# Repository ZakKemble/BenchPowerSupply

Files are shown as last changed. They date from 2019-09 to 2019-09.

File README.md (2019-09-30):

Bench Power Supply
==================

A 7.5A adjustable output bench power supply designed to be used with a 19V laptop power supply.

https://blog.zakkemble.net/laptop-bench-power-supply/

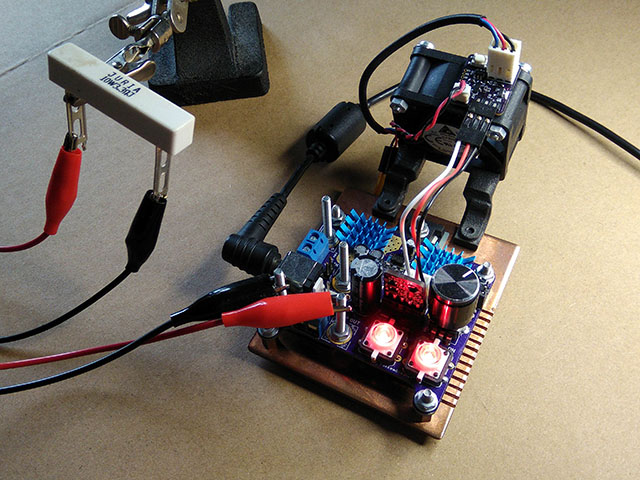
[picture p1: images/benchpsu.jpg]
PSU pic


---

Zak Kemble

contact@zakkemble.net

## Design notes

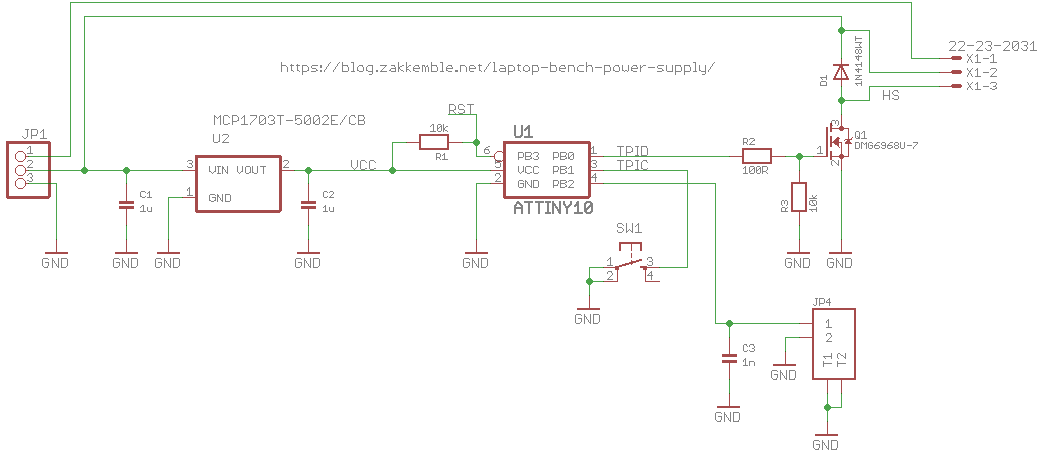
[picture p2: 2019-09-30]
hardware/fanCtrl_schematic.png

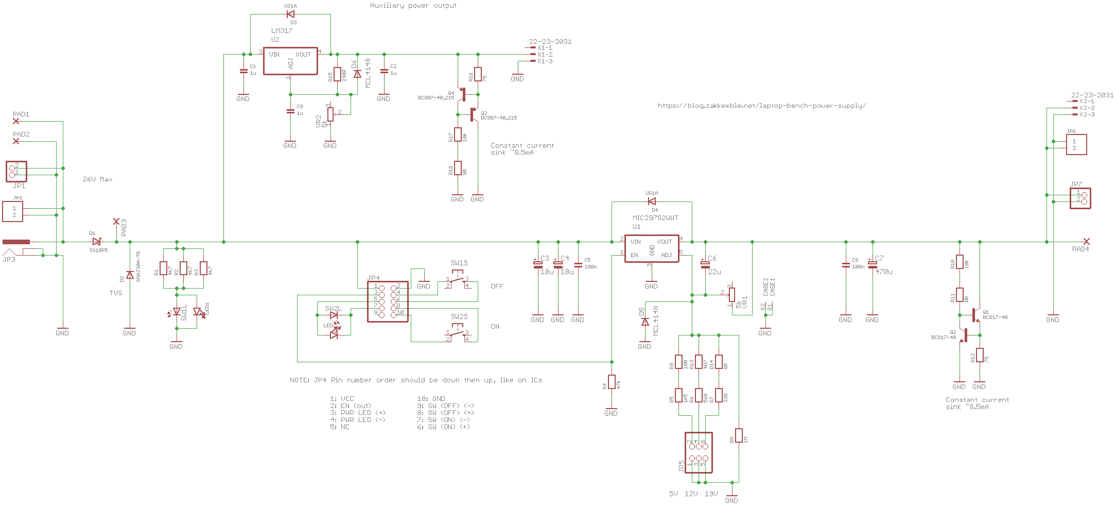
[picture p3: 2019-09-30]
hardware/reg_MIC29752_schematic.png

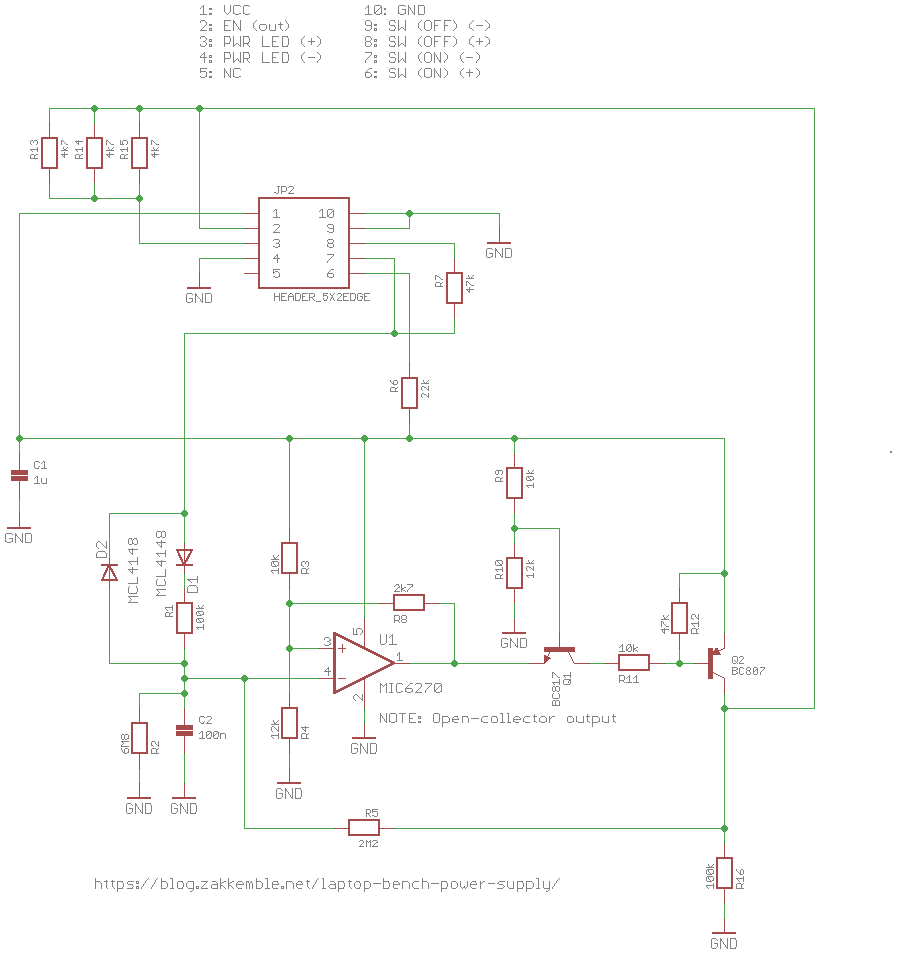
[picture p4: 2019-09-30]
hardware/control1_schematic.png

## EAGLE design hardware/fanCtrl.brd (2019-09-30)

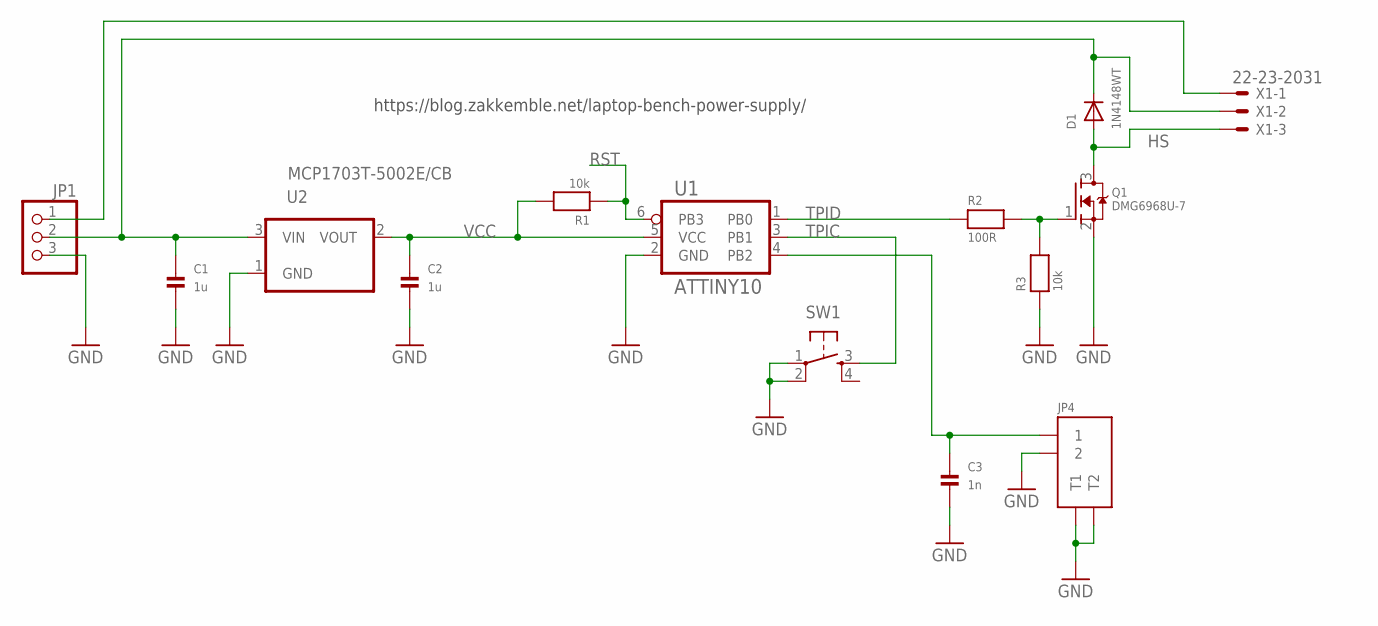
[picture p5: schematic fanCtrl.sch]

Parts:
C1, C2: 1u; _0603MP
C3: 1n; 0402_SMALL
D1: 1N4148WT; SOD-523
JP1: PINHD-1X3; 1X03
JP4: 2WAY
Q1: DMG6968U-7; SOT23-W
R1, R3: 10k; 0402_SMALL
R2: 100R; 0402_SMALL
SW1: SPST_TACTG75_3X4; TACT_SMD5
U1: ATTINY10; SOT23-6_SM_PAD
U2: MCP1703T-5002E/CB; SOT-23
X1: 22-23-2031

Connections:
GND: C1.2, C2.2, C3.2, JP1.3, JP4.P$2 (2), JP4.TAB$1 (T1), JP4.TAB$2 (T2), Q1.2 (S), R3.1, SW1.1, SW1.2 (P1), U1.2 (GND), U2.1 (GND)
HS: D1.A, Q1.3 (D), X1.3
unnamed: Q1.1 (G), R2.2, R3.2
unnamed: C3.1, JP4.P$1 (1), U1.4 (PB2)
unnamed: C1.1, D1.K (C), JP1.2, U2.3 (VIN), X1.2
unnamed: JP1.1, X1.1
RST: R1.1, U1.6 (PB3)
TPIC: SW1.3 (S), U1.3 (PB1)
TPID: R2.1, U1.1 (PB0)
VCC: C2.1, R1.2, U1.5 (VCC), U2.2 (VOUT)

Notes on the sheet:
https://blog.zakkemble.net/laptop-bench-power-supply/

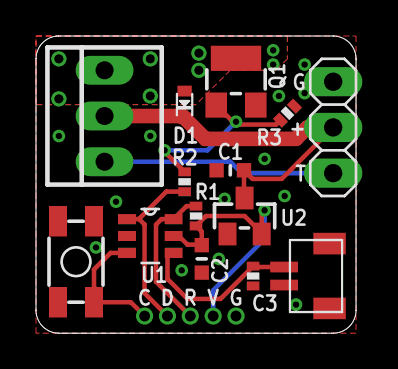
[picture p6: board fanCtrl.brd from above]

Board: 2 copper layers, 17.8 x 16.5 mm, 14 parts (0 on the bottom side), 10 nets.

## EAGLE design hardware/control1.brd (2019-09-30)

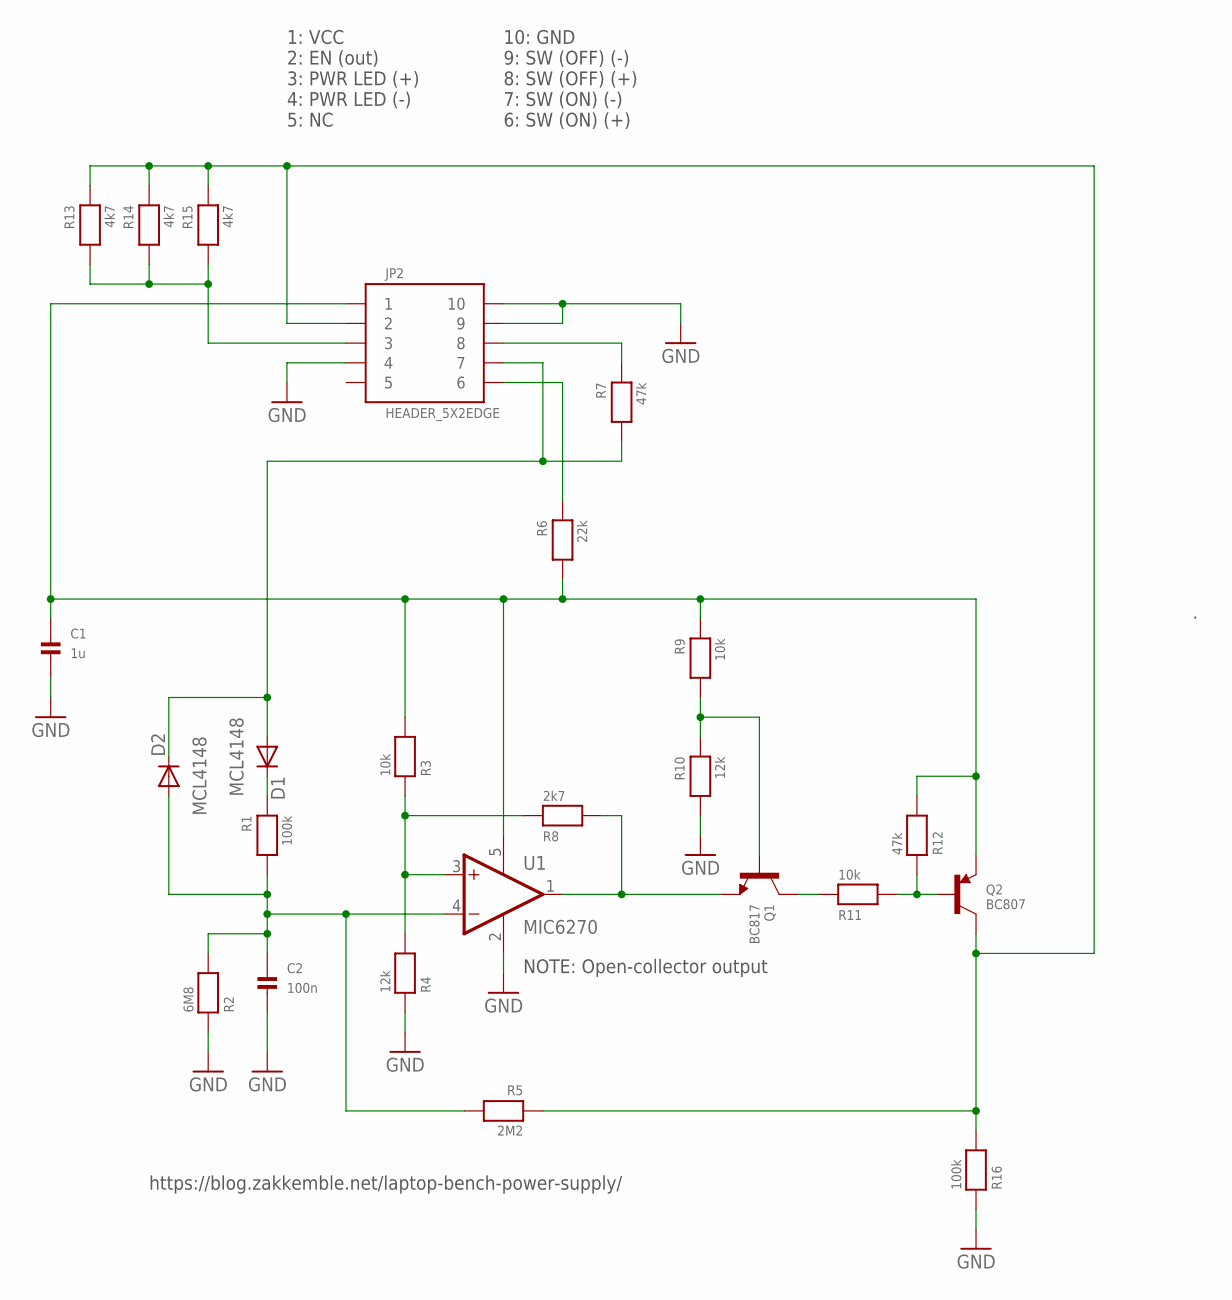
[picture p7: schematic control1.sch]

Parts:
C1: 1u; 0402
C2: 100n; _0603MP
D1, D2: MCL4148; MICROMELF-R
JP2: HEADER_5X2EDGE; HEADER_EDGE_5X2
Q1: BC817; SOT23-WIDE
Q2: BC807; SOT23-WIDE
R1, R16: 100k; 0402
R2: 6M8; 0402
R3, R9, R11: 10k; 0402
R4, R10: 12k; 0402
R5: 2M2; 0402
R6: 22k; 0402
R7, R12: 47k; 0402
R8: 2k7; 0402
R13, R14, R15: 4k7; 0402
U1: MIC6270; SOT95P275X110-5N

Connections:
GND: C1.2, C2.2, JP2.4, JP2.9, JP2.10, R2.1, R4.1, R10.2, R16.1, U1.2 (GND)
unnamed: C1.1, JP2.1, Q2.2 (E), R3.2, R6.2, R9.1, R12.2, U1.5 (V+)
unnamed: JP2.8, R7.1
unnamed: JP2.3, R13.2, R14.2, R15.2
unnamed: R3.1, R4.2, R8.1, U1.3 (+IN)
unnamed: C2.1, D2.A, R1.2, R2.2, R5.2, U1.4 (-IN)
unnamed: JP2.6, R6.1
unnamed: JP2.2, Q2.3 (C), R5.1, R13.1, R14.1, R15.1, R16.2
unnamed: Q1.3 (C), R11.1
unnamed: Q2.1 (B), R11.2, R12.1
unnamed: Q1.2 (E), R8.2, U1.1 (OUT)
unnamed: Q1.1 (B), R9.2, R10.1
unnamed: D1.A, D2.C, JP2.7, R7.2
unnamed: D1.C, R1.1

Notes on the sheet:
NOTE: Open-collector output
1: VCC 2: EN (out) 3: PWR LED (+) 4: PWR LED (-) 5: NC
10: GND 9: SW (OFF) (-) 8: SW (OFF) (+) 7: SW (ON) (-) 6: SW (ON) (+)
https://blog.zakkemble.net/laptop-bench-power-supply/

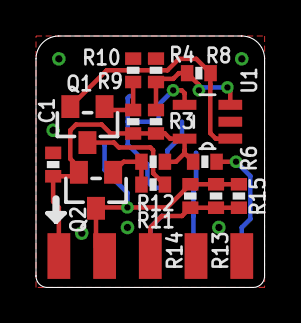
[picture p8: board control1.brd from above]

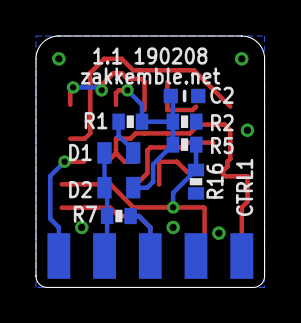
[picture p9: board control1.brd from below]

Board: 2 copper layers, 12.7 x 14.0 mm, 24 parts (8 on the bottom side), 14 nets.

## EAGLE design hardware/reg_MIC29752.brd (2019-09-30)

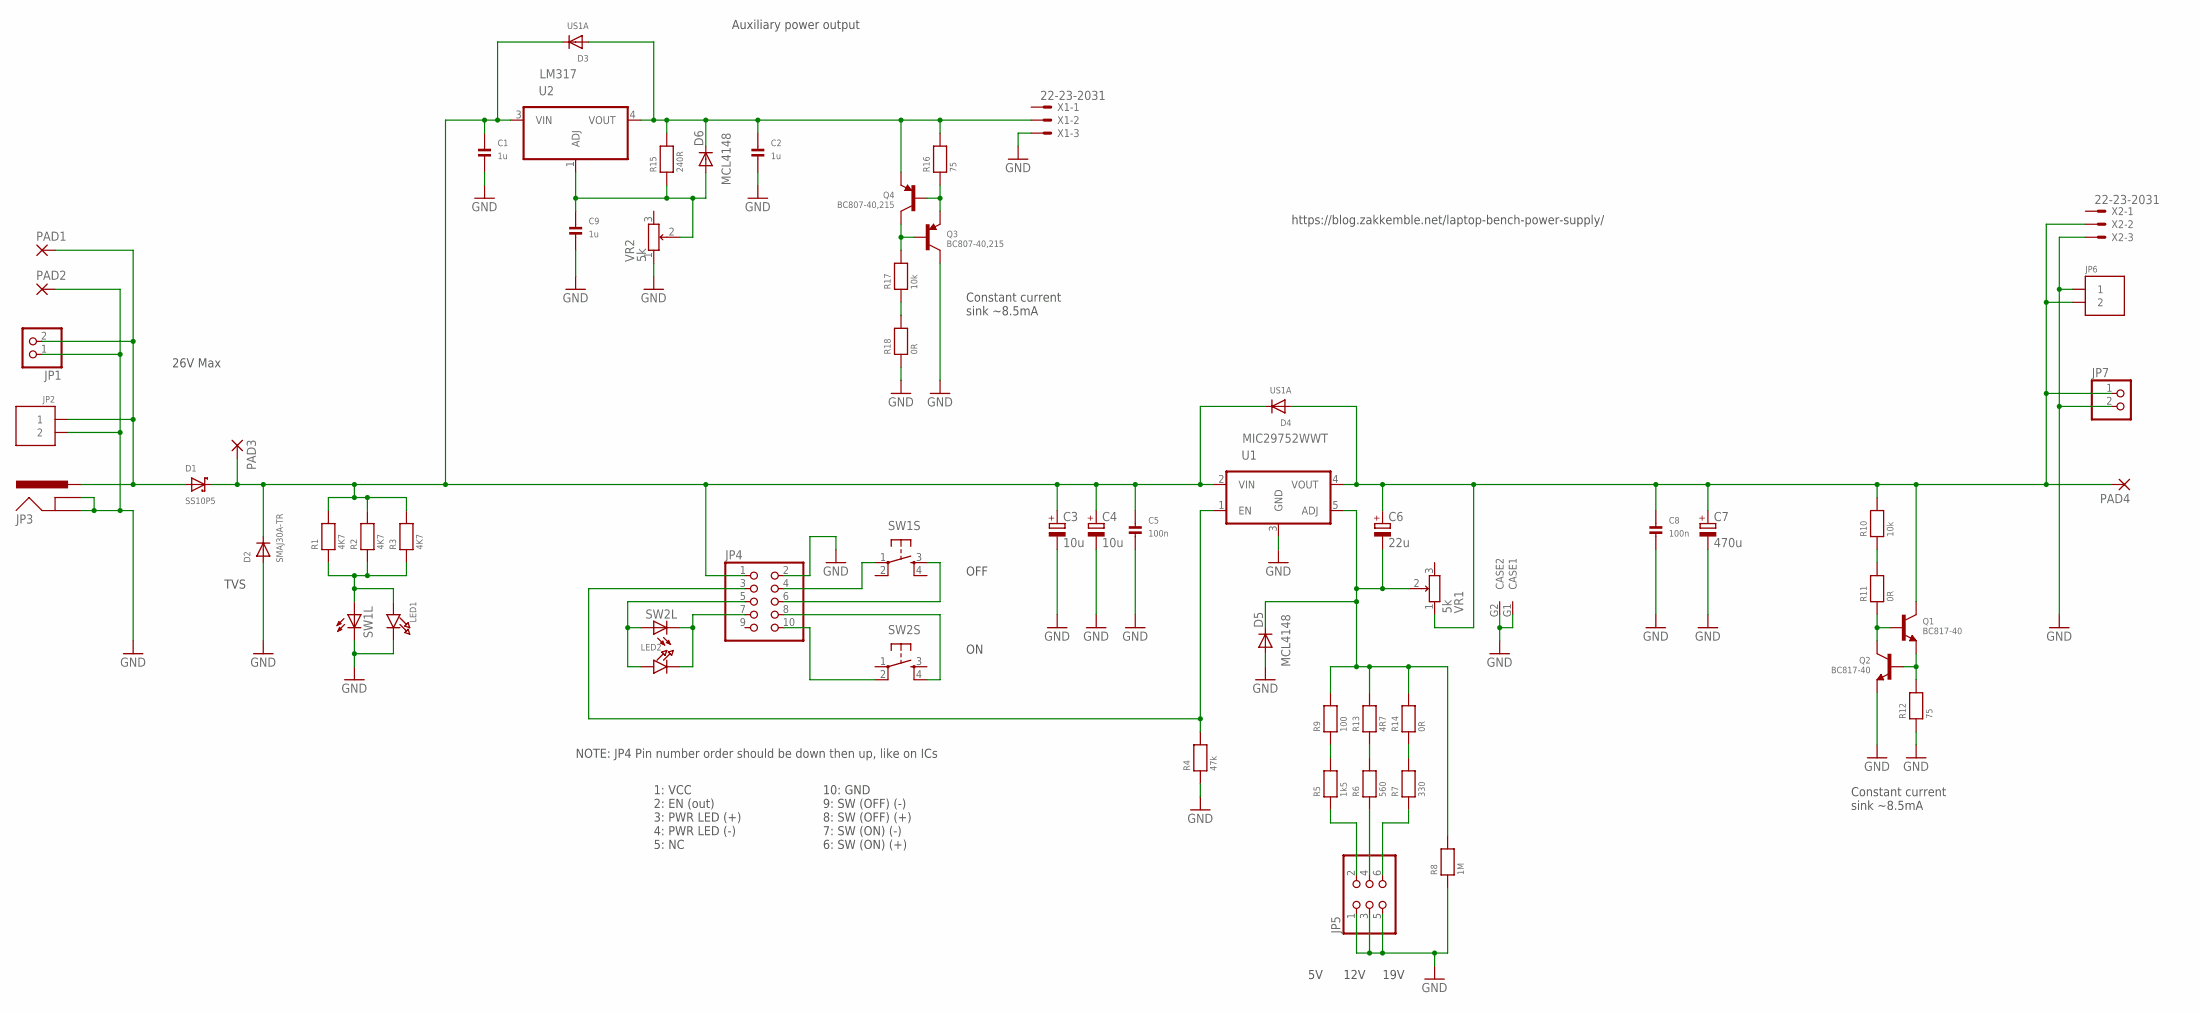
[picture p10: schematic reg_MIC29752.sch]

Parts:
C1, C2, C9: 1u; 0805_NO_OUTLINE
C3, C4: 10u; E2-5
C5, C8: 100n; _0603MP
C6: 22u; E2-4
C7: 470u; E5-10,5
D1: SS10P5; TO-277A
D2: SMAJ30A-TR; SMADIODE
D3, D4: US1A; SMADIODE
D5, D6: MCL4148; MICROMELF-R
JP1, JP7: PINHD-1X2; 1X02
JP2, JP6: TERM_BLOCK_2WAY; TERM_2WAY
JP3: POWER_JACKPTH_HIGHCURRENT; POWER_JACK_PTH_HIGHCURRENT
JP4: PINHD-2X5; 2X05
JP5: PINHD-2X3; 2X03
LED1, LED2: LED0603_NOOUTLINE; CHIPLED_0603_NOOUTLINE
PAD1, PAD2, PAD3, PAD4: WIREPAD-3.81,2SCREW-3MM; SCREWPAD-3MM
Q1: BC817-40; SOT23-W
Q2: BC817-40; SOT23-WIDE
Q3: BC807-40,215; SOT23-W
Q4: BC807-40,215; SOT23-WIDE
R1, R2, R3: 4K7; 0402
R4: 47k; 0402
R5: 1k5; 0402
R6: 560; 0402
R7: 330; 0402
R8: 1M; 0402
R9: 100; 0402
R10, R17: 10k; 0402
R11, R14, R18: 0R; 0402
R12, R16: 75; 0402
R13: 4R7; 0402
R15: 240R; 0402
SW1, SW2: SPST_TACT_LED12MM_TH; TACT_TH_12MM_LED
U1: MIC29752WWT; TO247-5-REVERSE
U2: LM317; DPAK
VR1: 5k; RV09
VR2: 5k; TRIMPOT_BOURNS3MM
X1, X2: 22-23-2031

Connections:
GND: C1.2, C2.2, C3.-, C4.-, C5.2, C7.-, C8.2, C9.2, D2.A, D5.A, JP1.1, JP2.2, JP3.C1 (GNDBREAK), JP3.C2 (GNDBREAK), JP3.C3 (GNDBREAK), JP3.C4 (GNDBREAK), JP3.GND, JP4.2, JP5.1, JP5.3, JP5.5, JP6.1, JP7.2, LED1.C, PAD2.1, Q2.2 (E), Q3.3 (C), R4.1, R8.1, R12.1, R18.1, SW1.5 (C), U1.3 (GND), VR1.G1 (CASE1), VR1.G2 (CASE2), VR2.1 (1A), X1.3, X2.3
unnamed: C1.1, C3.+, C4.+, C5.1, D1.K (C), D2.C, D3.C, D4.C, JP4.1, PAD3.1, R1.2, R2.2, R3.2, U1.2 (VIN), U2.3 (VIN)
unnamed: LED1.A, R1.1, R2.1, R3.1, SW1.6 (A)
unnamed: D1.1 (A), D1.2 (A), JP1.2, JP2.1, JP3.PWR, PAD1.1
unnamed: R5.2, R9.1
unnamed: JP4.7, LED2.C, SW2.5 (C)
unnamed: R10.1, R11.2
unnamed: R6.2, R13.1
unnamed: JP4.10, SW2.2 (P1)
unnamed: JP4.8, SW2.4 (S1)
unnamed: C2.1, D3.A, D6.C, Q4.2 (E), R15.2, R16.2, U2.4 (VOUT), X1.2
unnamed: R7.2, R14.1
unnamed: JP4.6, SW1.3 (S)
unnamed: JP4.4, SW1.1
unnamed: C6.-, D5.C, R8.2, R9.2, R13.2, R14.2, U1.5 (ADJ), VR1.2 (1S)
unnamed: JP5.6, R7.1
unnamed: JP5.4, R6.1
unnamed: C9.1, D6.A, R15.1, U2.1 (ADJ), VR2.2 (1S)
unnamed: C6.+, C7.+, C8.1, D4.A, JP6.2, JP7.1, PAD4.1, Q1.3 (C), R10.2, U1.4 (VOUT), VR1.1 (1A), X2.2
unnamed: JP5.2, R5.1
unnamed: Q1.2 (E), Q2.1 (B), R12.2
unnamed: Q1.1 (B), Q2.3 (C), R11.1
unnamed: Q3.2 (E), Q4.1 (B), R16.1
unnamed: Q3.1 (B), Q4.3 (C), R17.2
unnamed: R17.1, R18.2
unnamed: JP4.3, R4.2, U1.1 (EN)
unnamed: JP4.5, LED2.A, SW2.6 (A)

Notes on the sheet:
1: VCC 2: EN (out) 3: PWR LED (+) 4: PWR LED (-) 5: NC
10: GND 9: SW (OFF) (-) 8: SW (OFF) (+) 7: SW (ON) (-) 6: SW (ON) (+)
NOTE: JP4 Pin number order should be down then up, like on ICs
OFF
Constant current sink ~8.5mA
Auxiliary power output
https://blog.zakkemble.net/laptop-bench-power-supply/
12V
19V
26V Max
TVS

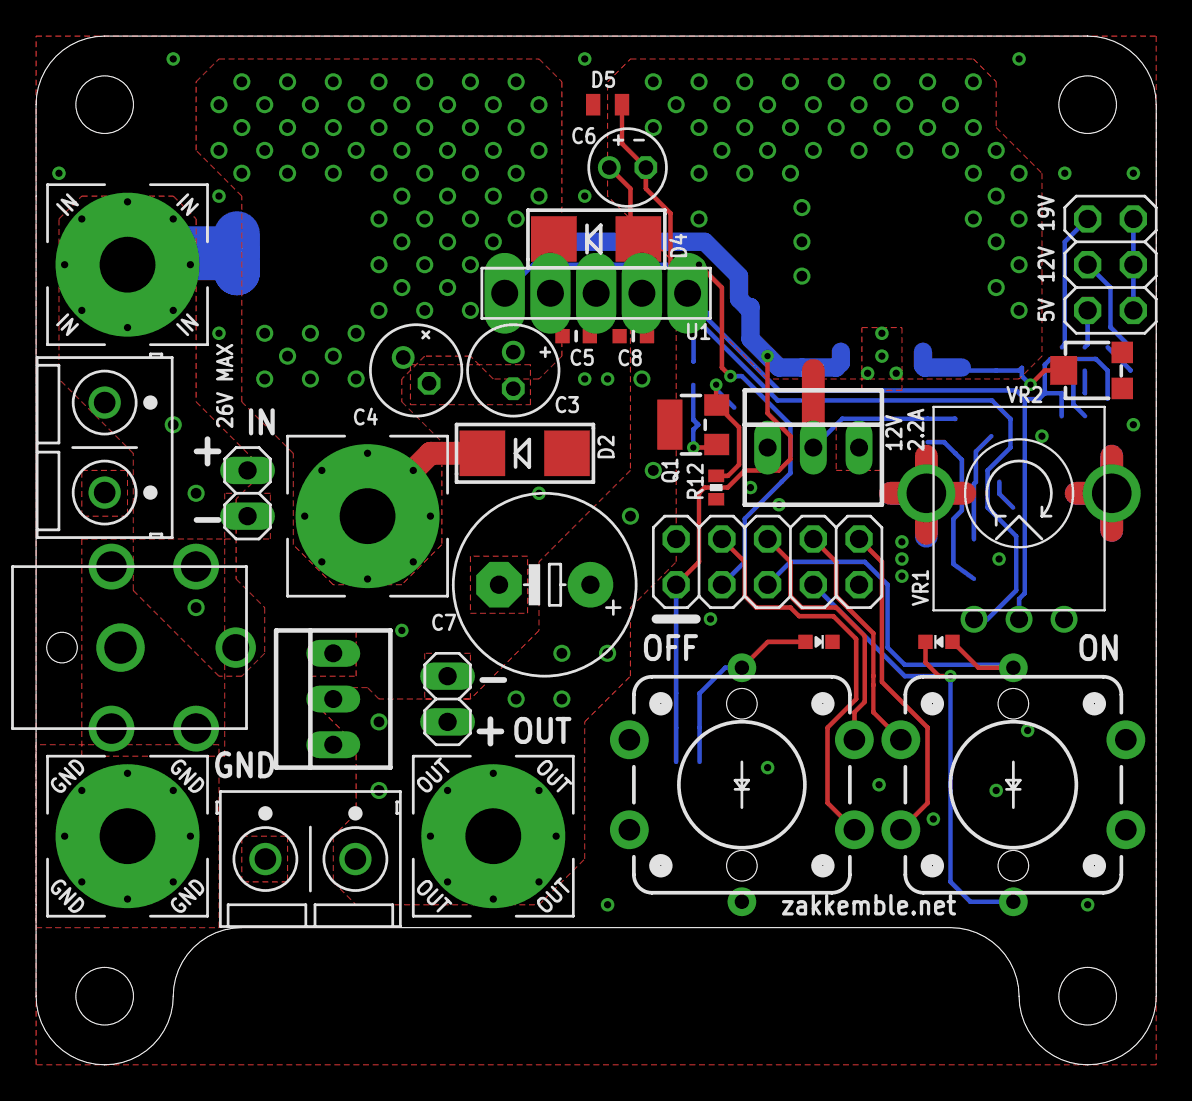
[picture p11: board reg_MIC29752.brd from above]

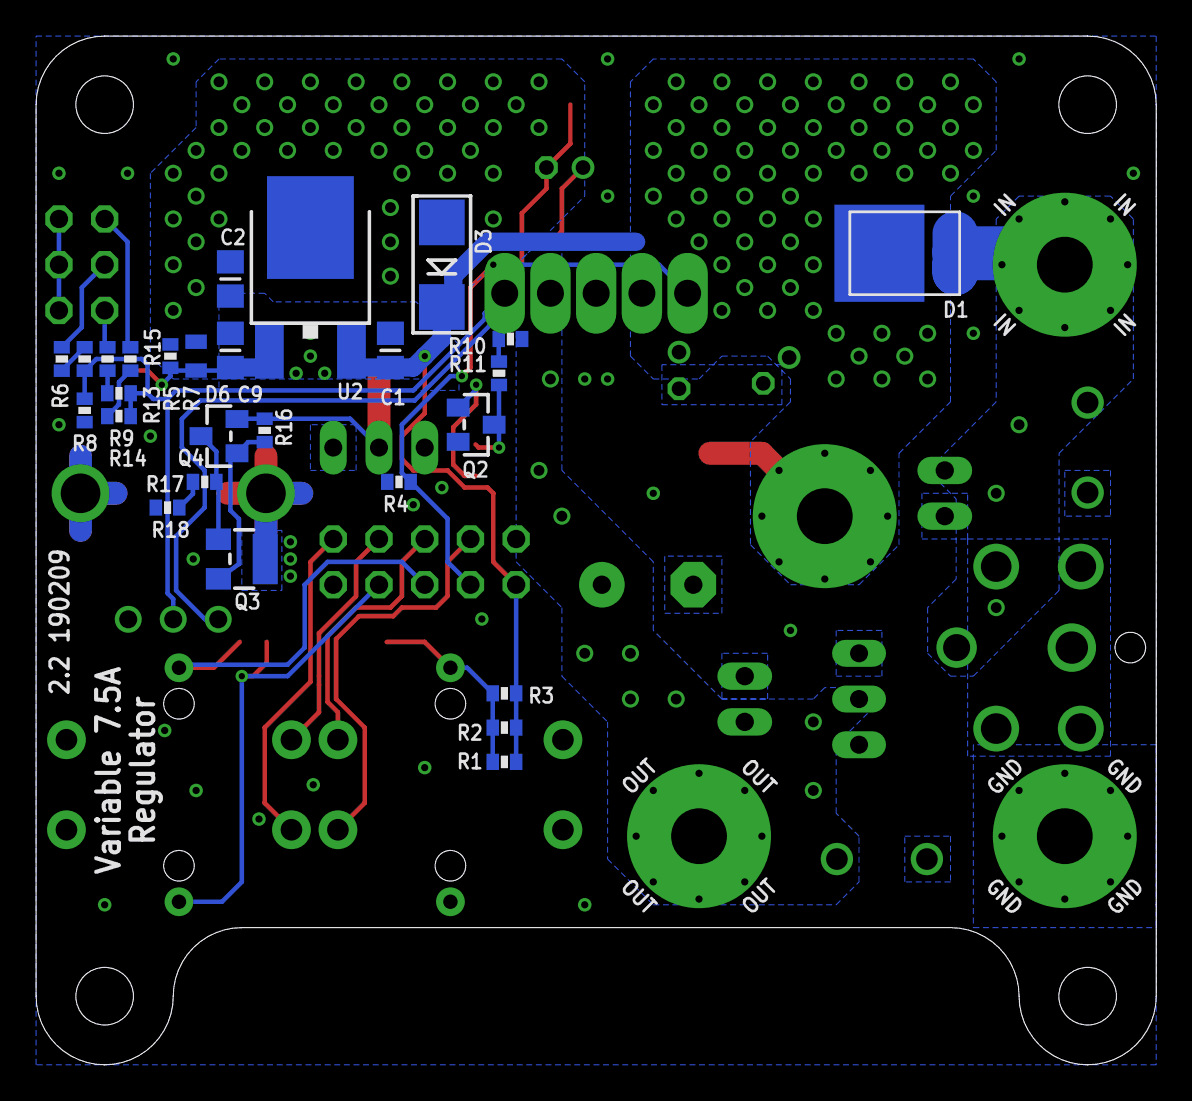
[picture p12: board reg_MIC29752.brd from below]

Board: 2 copper layers, 62.2 x 57.1 mm, 58 parts (27 on the bottom side), 27 nets.

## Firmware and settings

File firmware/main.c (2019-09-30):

/*
 * Project: Fan Controller for Bench Power Supply
 * Author: Zak Kemble, contact@zakkemble.net
 * Copyright: (C) 2019 by Zak Kemble
 * License: 
 * Web: https://blog.zakkemble.net/laptop-bench-power-supply/
 */

#include <stdint.h>
#include <avr/io.h>
#include <avr/power.h>
#include <avr/wdt.h>
#include <avr/interrupt.h>
#include <avr/sleep.h>
#include <util/delay.h>

#define FAN_OVERRIDE_NONE	0
#define FAN_OVERRIDE_ON		1
#define FAN_OVERRIDE_OFF	2

#define FAN_COOL_TIME		125 // 125 * 64ms = 8s // Keep fan on for this much longer after COOL_VAL has been reached
#define TEMP_MEASURE_INTERVAL	32 // 32 * 64ms = 2s // How often to measure temperature

// Temperature sensor resistance is 10k @ 22C
// Sensor resistance goes down as temperature goes up
// Pullup resistance is around 40k
// Lower value = hotter
#define HOT_VAL				23 // Sense: 4k @ ??C
#define COOL_VAL			27

#define WDT_INT_RESET()		(WDTCSR |= _BV(WDIE)|_BV(WDE)) // NOTE: Setting WDIE also enables global interrupts
#define WDT_TIMEDOUT() (!(WDTCSR & _BV(WDIE)))

#define FAN_ON() (PORTB |= _BV(PORTB0))
#define FAN_OFF() (PORTB &= ~_BV(PORTB0))
#define BTN_ISPRESSED() (!(PINB & _BV(PINB1)))

// PB0 = Fan out
// PB1 = Switch in
// PB2 = Temp sense ADC

static uint8_t rstflr_mirror __attribute__((section(".noinit,\"aw\",@nobits;"))); // BUG: https://github.com/qmk/qmk_firmware/issues/3657

void get_rstflr(void) __attribute__((naked, used, section(".init3")));
void get_rstflr()
{
	rstflr_mirror = RSTFLR;
	RSTFLR = 0;

	//wdt_disable(); 
	wdt_enable(WDTO_60MS);
}

int main(void)
{
	clock_prescale_set(CPU_DIV);

	DDRB |= _BV(DDB0);
	PUEB |= _BV(PUEB1);

	ACSR = _BV(ACD); // Power off analogue comparator

	// Setup ADC
	ADMUX = _BV(MUX1);
	ADCSRA = _BV(ADIE)|_BV(ADPS2)|_BV(ADPS0);
	DIDR0 = _BV(ADC2D);

	power_all_disable(); // Power off everything else

	uint8_t now = 0;
	uint8_t lastMeasureTemp = 0;
	uint8_t lastHotTime = (0 - FAN_COOL_TIME) + 31; // Turn fan on for 2 seconds at power on
	uint8_t hot = 0;
	uint8_t btnIsPressed = 0;
	uint8_t fanOverride = FAN_OVERRIDE_NONE;
	
	sei();

	// Was reset by the watchdog (mainly for debugging)
	if(rstflr_mirror & _BV(WDRF))
	{
		while(1)
		{
			// _delay_ms() is giving some asm error (avr-libc bug? GCC 8.3.0)
			for(uint16_t i=0;i<20000;i++)
			{
				WDT_INT_RESET();
				_delay_us(100);
			}
			//_delay_ms(2000);
		
			FAN_ON();

			// _delay_ms() is giving some asm error (avr-libc bug? GCC 8.3.0)
			for(uint16_t i=0;i<5000;i++)
			{
				WDT_INT_RESET();
				_delay_us(100);
			}
			//_delay_ms(500);
		
			FAN_OFF();
		}
	}

	WDT_INT_RESET();

	while(1)
	{
		// Timer stuff, increments every 64ms from the WDT
		// Also turns the WDT back on
		if(WDT_TIMEDOUT())
		{
			WDT_INT_RESET();
			now++;
		}

		if((uint8_t)(now - lastMeasureTemp) >= TEMP_MEASURE_INTERVAL)
		{
			// Pullup enable
			PUEB |= _BV(PUEB2);

			lastMeasureTemp = now;

			// Wait for a bit for voltage to stabilize
			// _delay_ms() is giving some asm error (avr-libc bug? GCC 8.3.0)
			for(uint8_t i=0;i<10;i++)
				_delay_us(100);
			//_delay_ms(1);

			// Do an ADC convertion
			power_adc_enable();
			ADCSRA |= _BV(ADEN)|_BV(ADSC);
			set_sleep_mode(SLEEP_MODE_ADC);
			sleep_mode();
			loop_until_bit_is_clear(ADCSRA, ADSC); // In case we wakeup from another interrupt before the convertion completes
			uint8_t val = ADCL;
			ADCSRA &= ~_BV(ADEN);
			power_adc_disable();

			// Pullup disable
			PUEB &= ~_BV(PUEB2);

			if(val > COOL_VAL)
				hot = 0;
			else if(val < HOT_VAL)
				hot = 1;
			// else we're between the hot and cool values (hysteresis)

			if(hot)
				lastHotTime = now;
		}

		// Don't need to bother with switch debouncing here since we only loop every ~64ms from the WDT
		if(BTN_ISPRESSED() && !btnIsPressed)
		{
			btnIsPressed = 1;

			if(fanOverride == FAN_OVERRIDE_NONE)
			{
				fanOverride = FAN_OVERRIDE_ON;
				FAN_ON();
			}
			else if(fanOverride == FAN_OVERRIDE_ON)
			{
				fanOverride = FAN_OVERRIDE_OFF;
				FAN_OFF();
			}
			else
			{
				fanOverride = FAN_OVERRIDE_NONE;
				if(!hot)
					lastHotTime = now - FAN_COOL_TIME;
			}
		}
		else if(!BTN_ISPRESSED() && btnIsPressed)
			btnIsPressed = 0;

		if(fanOverride == FAN_OVERRIDE_NONE)
		{
			if(hot || (uint8_t)(now - lastHotTime) < FAN_COOL_TIME)
				FAN_ON();
			else
			{
				FAN_OFF();
				lastHotTime = now - FAN_COOL_TIME;
			}
		}

		// Sleep if nothing to do
		cli();
		if(!WDT_TIMEDOUT())
		{
			set_sleep_mode(SLEEP_MODE_PWR_DOWN);
			sleep_enable();
			//sleep_bod_disable();
			sei();
			sleep_cpu();
			sleep_disable();
		}
		sei();
	}
}

EMPTY_INTERRUPT(WDT_vect);
EMPTY_INTERRUPT(ADC_vect);

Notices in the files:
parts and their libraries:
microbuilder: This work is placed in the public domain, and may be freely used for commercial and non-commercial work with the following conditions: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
